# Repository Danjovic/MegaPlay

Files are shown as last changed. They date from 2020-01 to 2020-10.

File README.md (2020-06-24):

# MegaPlay
Sega Genesis/Megadrive controller adapter with keypad emulation for Atari 5200

 This adapter lets you play Atari 5200 using a 6 button Sega Genesis controller yet providing full keypad control.
 
  The circuit is built around an Arduino Nano and two analog multiplexers.
  
  Interface with analog joystick is borrowed from "Low Priced MasterPlay clone adapter" and uses two resistors and a capacitor on each axis to convert the digital directionals into equivalent charging time for minimum, medium and maximum position on each axis.

  Keypad presses are emulated by activating a pair of analog multiplexers. Only 1 (one) keypress can be simulated at a time. 
  When there is no key pressed the "output" multiplexer is inhibited. 
  
  Buttons are mapped as follows:

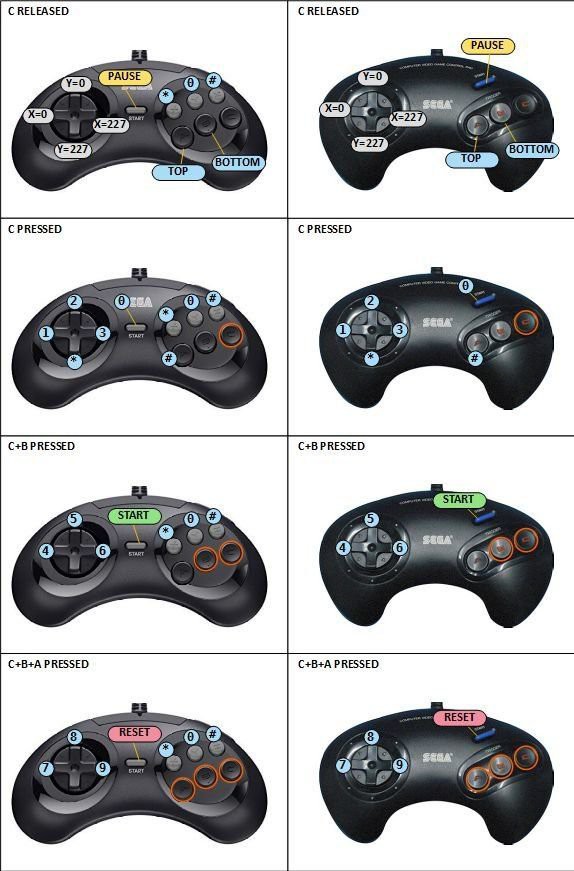
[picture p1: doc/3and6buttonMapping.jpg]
Buttons Mapping


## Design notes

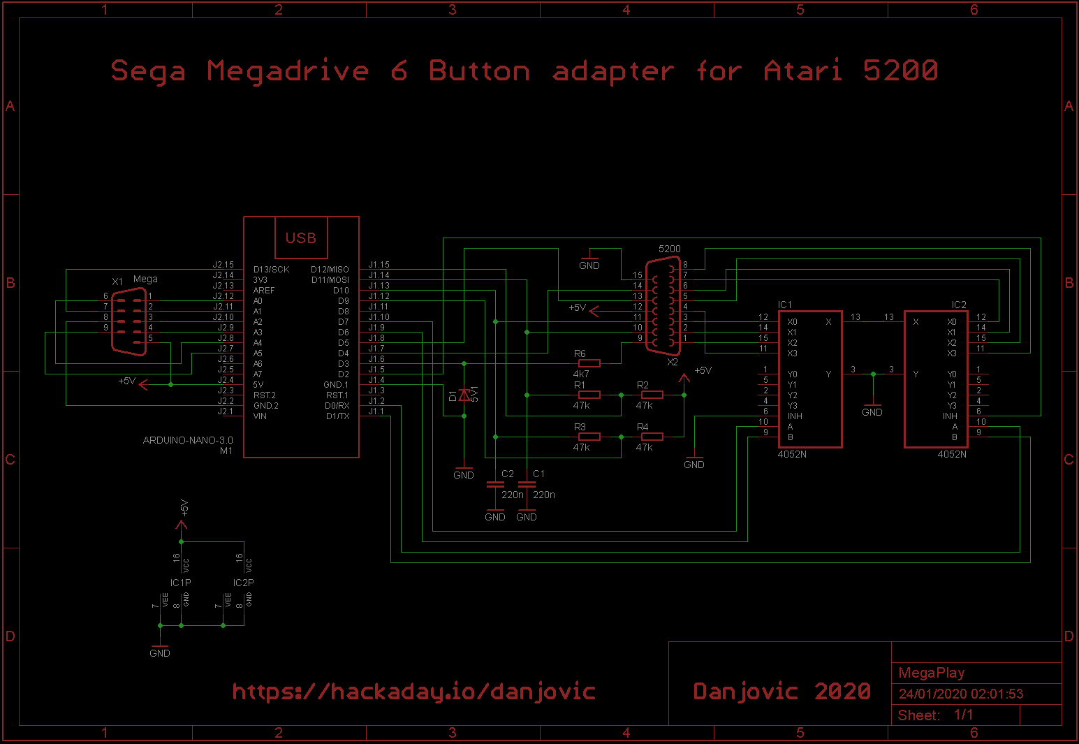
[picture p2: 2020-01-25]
circuit/MegaPlaySchematics.png

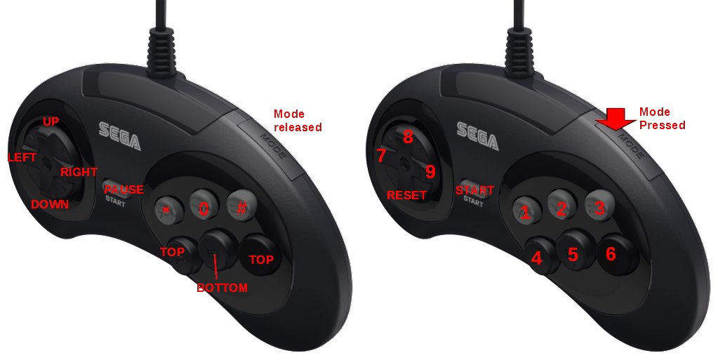
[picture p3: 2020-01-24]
doc/MegaPlay.png

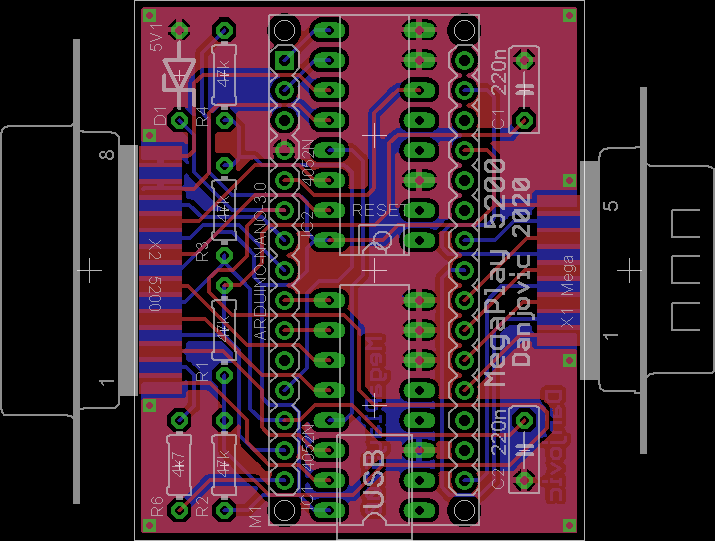
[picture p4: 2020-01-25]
doc/MegaPlayBoard.png

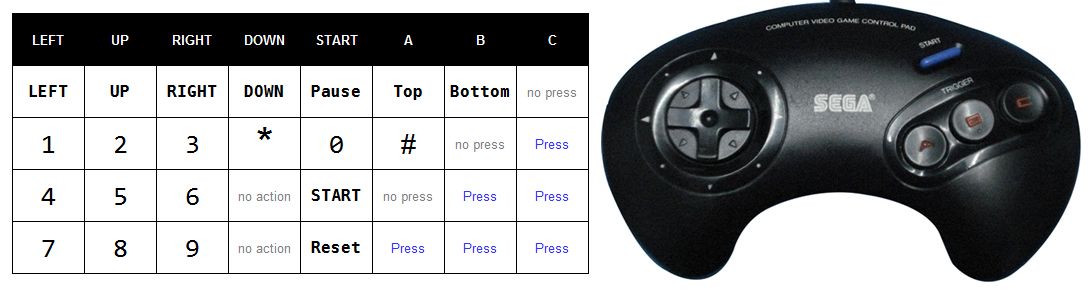
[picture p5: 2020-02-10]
doc/3Button mapping.jpg

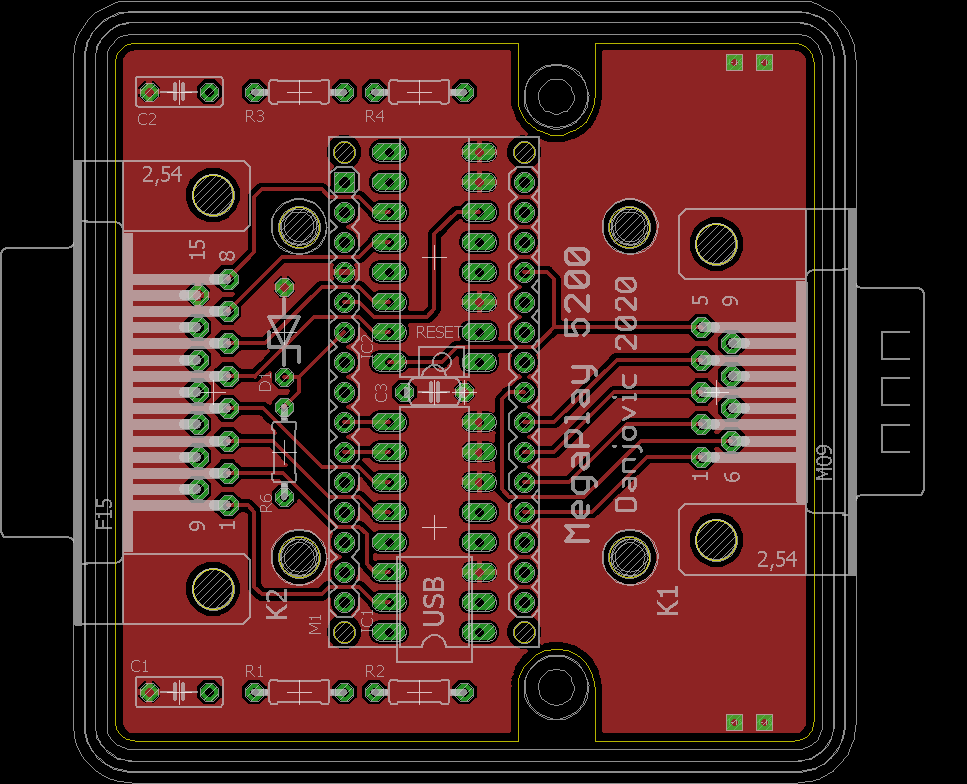
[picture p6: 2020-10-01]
doc/MegaPlayBoard-HammondBox.png

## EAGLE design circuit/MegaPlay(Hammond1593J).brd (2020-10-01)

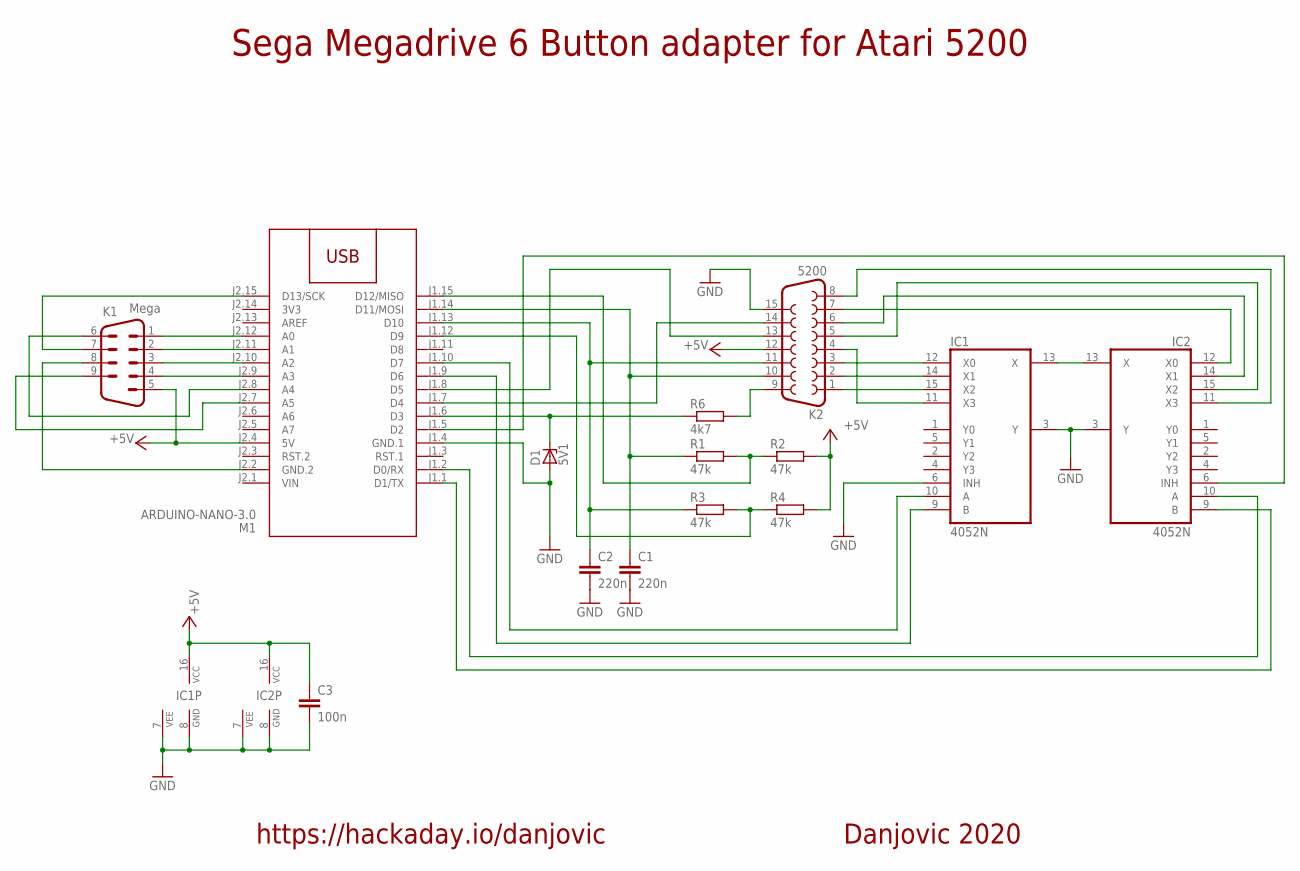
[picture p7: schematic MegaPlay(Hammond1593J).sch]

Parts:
C1, C2: 220n; C050-025X075
C3: 100n; C050-024X044
D1: 5V1; ZDIO-7.5
IC1, IC2: 4052N; DIL16
K1: Mega; M09H
K2: 5200; F15H
M1: ARDUINO-NANO-3.0
R1, R2, R3, R4: 47k; 0204/7
R6: 4k7; 0204/7

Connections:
3V3: M1.J2.14 (3V3)
+5V: C3.1, IC1.16 (VCC), IC2.16 (VCC), K1.5, K2.12, M1.J2.4 (5V), R2.2, R4.2
GND: C1.2, C2.2, C3.2, D1.A, IC1.3 (Y), IC1.6 (INH), IC1.7 (VEE), IC1.8 (GND), IC2.3 (Y), IC2.7 (VEE), IC2.8 (GND), K2.15, M1.J1.4 (GND.1)
unnamed: M1.J1.12 (D9), R3.2, R4.1
unnamed: IC1.15 (X2), K2.1
unnamed: IC1.13 (X), IC2.13 (X)
unnamed: IC1.14 (X1), K2.2
unnamed: IC1.12 (X0), K2.3
unnamed: IC1.11 (X3), K2.4
unnamed: IC2.15 (X2), K2.5
unnamed: IC2.14 (X1), K2.6
unnamed: IC2.12 (X0), K2.7
unnamed: K1.1, M1.J2.12 (A0)
unnamed: C1.1, K2.10, M1.J1.14 (D11/MOSI), R1.1
unnamed: M1.J1.15 (D12/MISO), R1.2, R2.1
unnamed: IC2.11 (X3), K2.8
unnamed: C2.1, K2.11, M1.J1.13 (D10), R3.1
unnamed: K2.13, M1.J1.8 (D5)
unnamed: K1.2, M1.J2.11 (A1)
unnamed: K1.3, M1.J2.10 (A2)
unnamed: K1.4, M1.J2.9 (A3)
unnamed: K1.7, M1.J2.15 (D13/SCK)
unnamed: K1.6, M1.J2.8 (A4)
unnamed: K1.9, M1.J2.7 (A5)
unnamed: K1.8, M1.J2.2 (GND.2)
unnamed: D1.C, M1.J1.6 (D3), R6.1
unnamed: IC2.6 (INH), M1.J1.5 (D2)
unnamed: K2.9, R6.2
unnamed: IC2.10 (A), M1.J1.2 (D0/RX)
unnamed: IC2.9 (B), M1.J1.1 (D1/TX)
unnamed: K2.14, M1.J1.7 (D4)
unnamed: IC1.10 (A), M1.J1.10 (D7)
unnamed: IC1.9 (B), M1.J1.9 (D6)
VIN: M1.J2.1 (VIN)

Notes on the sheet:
Sega Megadrive 6 Button adapter for Atari 5200
Danjovic 2020
https://hackaday.io/danjovic

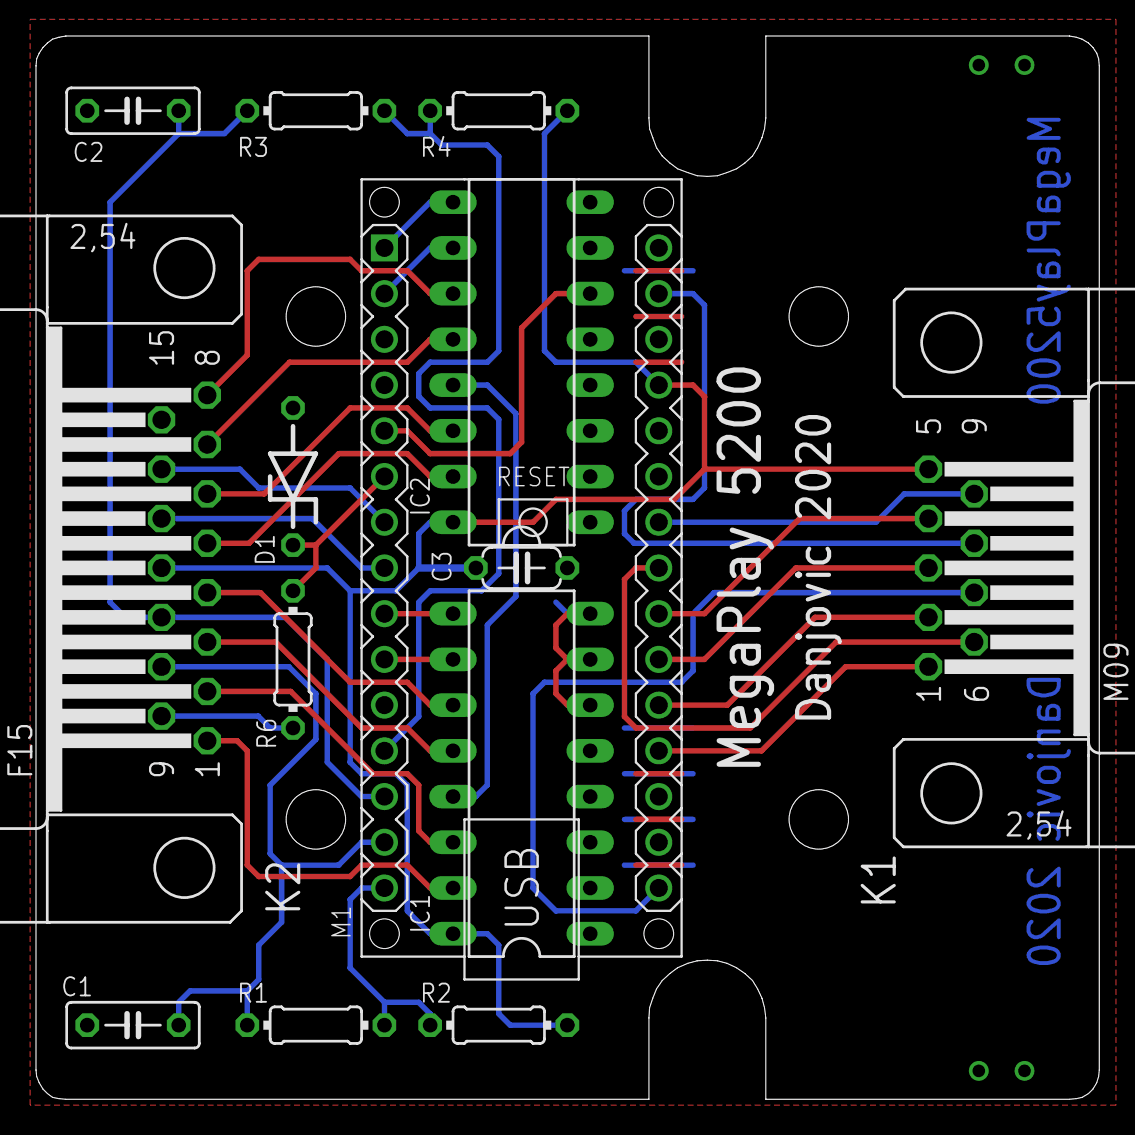
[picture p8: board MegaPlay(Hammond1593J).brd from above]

Board: 2 copper layers, 59.1 x 59.1 mm, 15 parts (0 on the bottom side), 32 nets.

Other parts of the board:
U$1: 1593J

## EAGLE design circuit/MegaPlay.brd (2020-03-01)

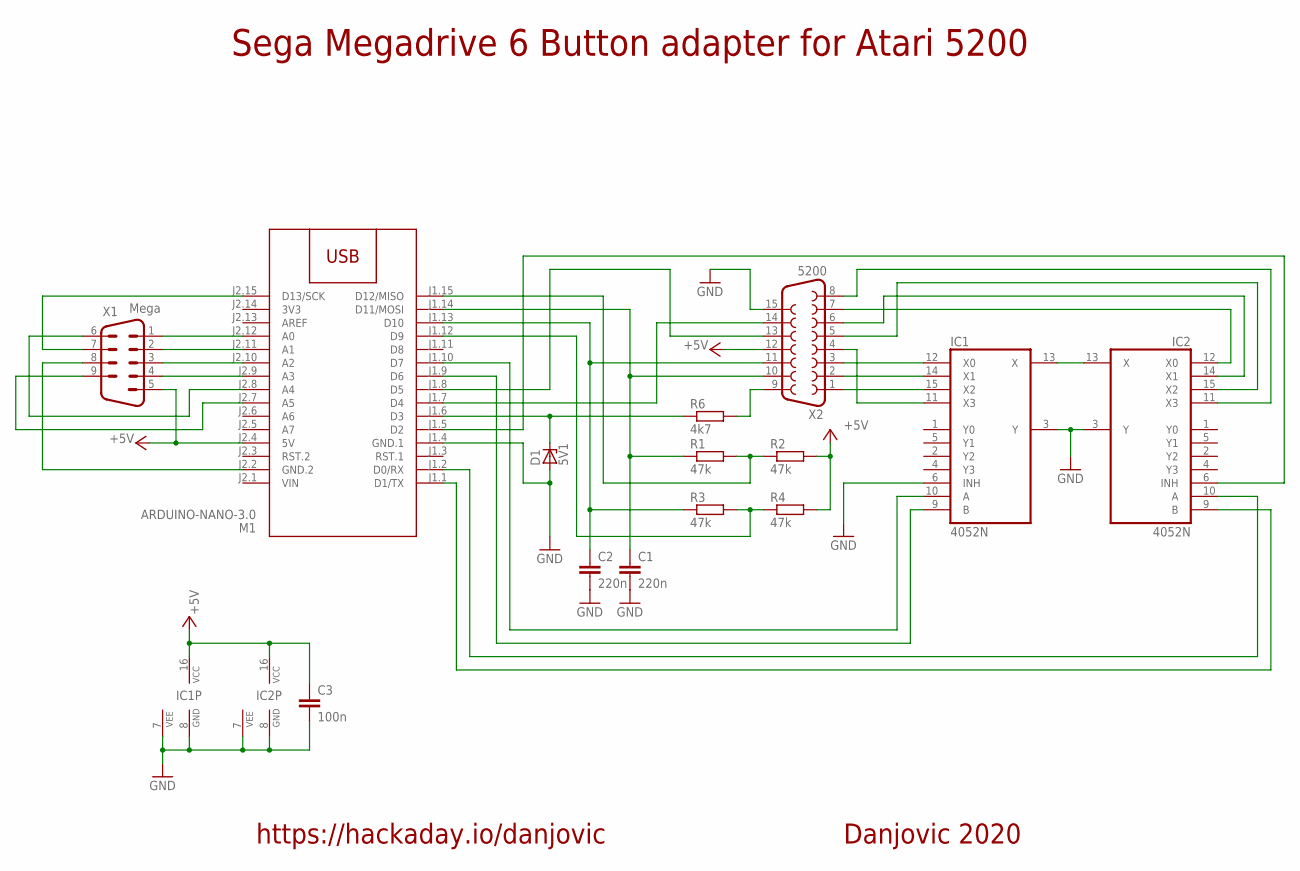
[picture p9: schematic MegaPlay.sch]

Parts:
C1, C2: 220n; C050-025X075
C3: 100n; C050-024X044
D1: 5V1; ZDIO-7.5
IC1, IC2: 4052N; DIL16
M1: ARDUINO-NANO-3.0
R1, R2, R3, R4: 47k; 0204/7
R6: 4k7; 0204/7
X1: Mega; M09D
X2: 5200; F15D

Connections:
3V3: M1.J2.14 (3V3)
+5V: C3.1, IC1.16 (VCC), IC2.16 (VCC), M1.J2.4 (5V), R2.2, R4.2, X1.5, X2.12
GND: C1.2, C2.2, C3.2, D1.A, IC1.3 (Y), IC1.6 (INH), IC1.7 (VEE), IC1.8 (GND), IC2.3 (Y), IC2.7 (VEE), IC2.8 (GND), M1.J1.4 (GND.1), X2.15
unnamed: M1.J1.12 (D9), R3.2, R4.1
unnamed: IC1.15 (X2), X2.1
unnamed: IC1.13 (X), IC2.13 (X)
unnamed: IC1.14 (X1), X2.2
unnamed: IC1.12 (X0), X2.3
unnamed: IC1.11 (X3), X2.4
unnamed: IC2.15 (X2), X2.5
unnamed: IC2.14 (X1), X2.6
unnamed: IC2.12 (X0), X2.7
unnamed: M1.J2.12 (A0), X1.1
unnamed: C1.1, M1.J1.14 (D11/MOSI), R1.1, X2.10
unnamed: M1.J1.15 (D12/MISO), R1.2, R2.1
unnamed: IC2.11 (X3), X2.8
unnamed: C2.1, M1.J1.13 (D10), R3.1, X2.11
unnamed: M1.J1.8 (D5), X2.13
unnamed: M1.J2.11 (A1), X1.2
unnamed: M1.J2.10 (A2), X1.3
unnamed: M1.J2.9 (A3), X1.4
unnamed: M1.J2.15 (D13/SCK), X1.7
unnamed: M1.J2.8 (A4), X1.6
unnamed: M1.J2.7 (A5), X1.9
unnamed: M1.J2.2 (GND.2), X1.8
unnamed: D1.C, M1.J1.6 (D3), R6.1
unnamed: IC2.6 (INH), M1.J1.5 (D2)
unnamed: R6.2, X2.9
unnamed: IC2.10 (A), M1.J1.2 (D0/RX)
unnamed: IC2.9 (B), M1.J1.1 (D1/TX)
unnamed: M1.J1.7 (D4), X2.14
unnamed: IC1.10 (A), M1.J1.10 (D7)
unnamed: IC1.9 (B), M1.J1.9 (D6)
VIN: M1.J2.1 (VIN)

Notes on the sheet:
Sega Megadrive 6 Button adapter for Atari 5200
Danjovic 2020
https://hackaday.io/danjovic

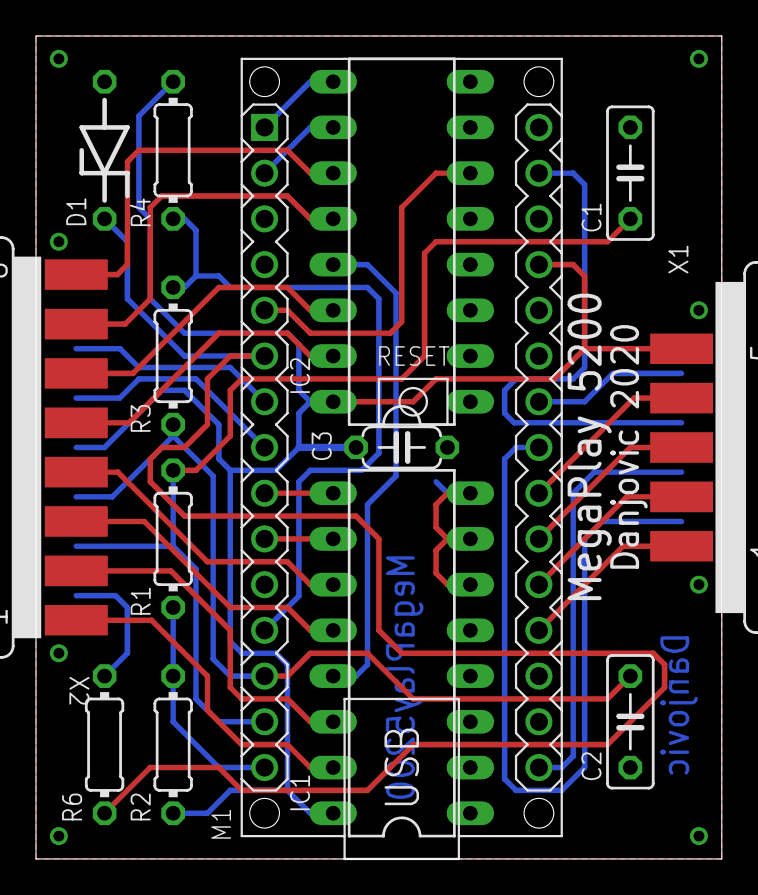
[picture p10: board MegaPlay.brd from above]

Board: 2 copper layers, 38.1 x 45.7 mm, 14 parts (0 on the bottom side), 32 nets.

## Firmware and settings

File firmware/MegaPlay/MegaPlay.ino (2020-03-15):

/*******************************************************************************
       __  __               ___ _           
      |  \/  |___ __ _ __ _| _ \ |__ _ _  _ 
      | |\/| / -_) _` / _` |  _/ / _` | || |
      |_|  |_\___\__, \__,_|_| |_\__,_|\_, |
                 |___/                 |__/ 

  MegaPlay adapter for Atari 5200 - Danjovic 2020 - danjovic@hotmail.com - https://hackaday.io/danjovic

  24 January 2020

  This adapter lets you play Atari 5200 using a 6 button Sega Genesis controller yet providing full keypad control.
  The circuit is built around an Arduino Nano and two analog multiplexers.
  Interface with analog joystick is borrowed from "Low Priced MasterPlay clone adapter" and uses two resistors and
  a capacitor on each axis to convert the digital directionals into equivalent charging time for minimum, medium and 
  maximum position on each axis.

  Keypad presses are emulated by activating a pair of analog multiplexers. Only 1 (one) keypress can be simulated at a time. 
  When there is no key pressed the "output" multiplexer is inhibited. Buttons are mapped as follows:

                    +------------------------------------------+
                    |           Modifier key(s) pressed        |
+----------+--------+-----------+----------+---------+---------+
|   Type   | Button |   none    |    C     |  C + B  |  C+B+A  |
+-----+----+--------+ ----------+----------+---------+---------+
|  6  | 3  | UP     |    UP     |    2     |    5    |    8    |
|  B  | B  | DOWN   |   DOWN    |    *     |    -    |    -    |
|  u  | u  | LEFT   |   LEFT    |    1     |    4    |    7    |
|  t  | t  | RIGHT  |   RIGHT   |    3     |    6    |    9    |
|  t  | t  |  A     |    Top    |    #     |    -    |    -    |
|  o  | o  |  B     |   Bottom  |    -     |    -    |    -    |
|  n  | n  |  C     |     -     |    -     |    -    |    -    |
|     |    | START  |   Pause   |    0     |  Start  |  Reset  |
|     +----+--------+-----------+----------+---------+---------+
|          |  X     |     *     |    *     |    *    |    *    |
|          |  Y     |     0     |    0     |    0    |    0    |
|          |  Z     |     #     |    #     |    #    |    #    |
+----------+--------+-----------+----------+---------+---------+ 

  Keypresses are emulated by activation of the following combination of signals. 
  The 'none' key state is issued by rising the INHIBT signal to disabe the output MUX.

        +------- Output Mux -MSbits-----+
  Input |   7       6       5       8   |
   Mux  |  0 0  |  0 1  |  1 0  |  1 1  |
   B A  +-------+-------+-------+-------+ 
   0 0  |   1   |   4   |   7   |   *   | 3
   0 1  |   2   |   5   |   8   |   0   | 2
   1 0  |   3   |   6   |   9   |   #   | 1
   1 1  | start | pause | reset |  none | 4
        +-------+-------+-------+-------+

  CAV Voltage on PIN 9 is connected to INT1 IRQ pin and is used to promptly turn off the timing pins whenever CAV drops to zero. 
  A zener diode as added to protect the AVR input, as the CAV voltage can reach up to 6.4Volts.



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
*/




/*******************************************************************************
 *         _      __ _      _ _   _             
 *      __| |___ / _(_)_ _ (_) |_(_)___ _ _  ___
 *     / _` / -_)  _| | ' \| |  _| / _ \ ' \(_-<
 *     \__,_\___|_| |_|_||_|_|\__|_\___/_||_/__/
 *                                              
 */

//#define DEBUG 1

 
#define _key1        ((0<<3)|(0<<2)|(0<<1)|(0<<0)) // 0
#define _key2        ((0<<3)|(0<<2)|(0<<1)|(1<<0)) // 1
#define _key3        ((0<<3)|(0<<2)|(1<<1)|(0<<0)) // 2
#define _keyStart    ((0<<3)|(0<<2)|(1<<1)|(1<<0)) // 3
#define _key4        ((0<<3)|(1<<2)|(0<<1)|(0<<0)) // 4
#define _key5        ((0<<3)|(1<<2)|(0<<1)|(1<<0)) // 5
#define _key6        ((0<<3)|(1<<2)|(1<<1)|(0<<0)) // 6
#define _keyPause    ((0<<3)|(1<<2)|(1<<1)|(1<<0)) // 7
#define _key7        ((1<<3)|(0<<2)|(0<<1)|(0<<0)) // 8
#define _key8        ((1<<3)|(0<<2)|(0<<1)|(1<<0)) // 9
#define _key9        ((1<<3)|(0<<2)|(1<<1)|(0<<0)) // 10
#define _keyReset    ((1<<3)|(0<<2)|(1<<1)|(1<<0)) // 11
#define _keyAsterisk ((1<<3)|(1<<2)|(0<<1)|(0<<0)) // 12
#define _key0        ((1<<3)|(1<<2)|(0<<1)|(1<<0)) // 13
#define _keyHash     ((1<<3)|(1<<2)|(1<<1)|(0<<0)) // 14
#define _keyNone     ((1<<3)|(1<<2)|(1<<1)|(1<<0)) // 15

#define inputMuxA       6
#define inputMuxB       7
#define outputMuxA      0
#define outputMuxB      1
#define outputMuxInhibt 2

#define genesisUp       A0
#define genesisDown     A1
#define genesisLeft     A2
#define genesisRigth    A3
#define genesisB        A4
#define genesisC        A5
#define genesisSelect   13

#define potXfull        11
#define potXhalf        12

#define potYfull        10
#define potYhalf        9

#define fireTop         4
#define fireBottom      5

enum controllerType {
  _6Button=0,
  _3Button,
  _unKnown =0xff
  };

#define buttonUp     (1<<0)
#define buttonDown   (1<<1)
#define buttonLeft   (1<<2)
#define buttonRight  (1<<3)
#define buttonB      (1<<4)
#define buttonC      (1<<5)
#define buttonA      (1<<6)
#define buttonStart  (1<<7)
#define buttonZ      (1<<8)
#define buttonY      (1<<9)
#define buttonX      (1<<10)
#define buttonMode   (1<<11)

/*******************************************************************************
 *                   _      _    _        
 *     __ ____ _ _ _(_)__ _| |__| |___ ___
 *     \ V / _` | '_| / _` | '_ \ / -_|_-<
 *      \_/\__,_|_| |_\__,_|_.__/_\___/__/
 *                                        
 */

uint8_t ScanGenesis(void);
void assertTopFire(void);
void releaseTopFire(void);
void assertBottomFire(void);
void releaseBottomFire(void);
void setMinimumY(void);
void setMaximumY(void);
void setMiddleY(void); 
void setMinimumX(void);
void setMaximumX(void);
void setMiddleX(void); 

static volatile uint8_t CAVoff;
uint16_t combinedButtons = 0;



/*******************************************************************************
 *      _     _                         _      
 *     (_)_ _| |_ ___ _ _ _ _ _  _ _ __| |_ ___
 *     | | ' \  _/ -_) '_| '_| || | '_ \  _(_-<
 *     |_|_||_\__\___|_| |_|  \_,_| .__/\__/__/
 *                                |_|          
 */

// External interrupt, triggers every time CAV voltage changes state.
ISR (INT1_vect, ISR_NAKED) { 
  asm volatile (
    "push __tmp_reg__\n\t"         //
    "in __tmp_reg__,__SREG__\n\t"  //  Save Context
    "push __tmp_reg__\n\t"         //  
    "clr __tmp_reg__\n\t"         // temp_reg=0 CAVoff = false
    "sbic %[PORTIN],3 \n\t"       // CAV has dropped?
    "rjmp _STORE\n\t"             // no update value
    "cbi %[PORTPOTS],2\n\t"       // yes, force pin Y to zero
    "sbi %[DDRPOTS],2\n\t"
    "cbi %[PORTPOTS],3\n\t"       // yes, force pin X to zero
    "sbi %[DDRPOTS],3\n\t"
    "inc __tmp_reg__\n\t"         // temp_reg=1 CAVoff = true                        
    "_STORE:\n\t"
     "sts %[flagCAVoff],__tmp_reg__\n\t" // store CAVoff flag value
    "pop __tmp_reg__\n\t"           //
    "out __SREG__,__tmp_reg__\n\t"  // Restore Context
    "pop __tmp_reg__\n\t"           //
    "reti \n\t"
    :[flagCAVoff] "=m"(CAVoff)
    :[PORTIN]"I" (_SFR_IO_ADDR(PIND)),[DDRPOTS]"I" (_SFR_IO_ADDR(DDRB)) ,[PORTPOTS]"I" (_SFR_IO_ADDR(PORTB)) 
    );  
  }



/*******************************************************************************
 *      ___      _             
 *     / __| ___| |_ _  _ _ __ 
 *     \__ \/ -_)  _| || | '_ \
 *     |___/\___|\__|\_,_| .__/
 *                       |_|   
 */
void setup() {
  // put your setup code here, to run once:

  pinMode(potXfull,INPUT);
  pinMode(potXhalf,OUTPUT);
  digitalWrite(potXhalf,HIGH);
  
  pinMode(potYfull,INPUT);
  pinMode(potYhalf,OUTPUT);
  digitalWrite(potYhalf,HIGH);  

  
  pinMode(genesisUp    ,INPUT_PULLUP);
  pinMode(genesisDown  ,INPUT_PULLUP);
  pinMode(genesisLeft  ,INPUT_PULLUP);
  pinMode(genesisRigth ,INPUT_PULLUP);
  pinMode(genesisB     ,INPUT_PULLUP);
  pinMode(genesisC     ,INPUT_PULLUP);
  pinMode(genesisSelect,OUTPUT);
  digitalWrite(genesisSelect,LOW);
  pinMode(outputMuxB,OUTPUT); 
  pinMode(outputMuxA,OUTPUT); 
  pinMode(inputMuxB,OUTPUT); 
  pinMode(inputMuxA,OUTPUT);   
  pinMode(outputMuxInhibt,OUTPUT);
  digitalWrite(outputMuxInhibt,HIGH);
  delay(5); // wait for genesis internal logic timeout

 
  // Setup interrupts
  EICRA = (0<<ISC11)| (1<<ISC10); //  Any logical change on INT1 generates an interrupt request.
  EIMSK = (1<<INT1);              //  enable external interrupts on pin INT1 (D3)
  EIFR =  (1<<INT1); // clear any pending interrupt
  
  sei();  // enable interrupts
#ifdef DEBUG
  Serial.begin(9600);
#endif
}




/*******************************************************************************
 *      __  __      _        _                  
 *     |  \/  |__ _(_)_ _   | |   ___  ___ _ __ 
 *     | |\/| / _` | | ' \  | |__/ _ \/ _ \ '_ \
 *     |_|  |_\__,_|_|_||_| |____\___/\___/ .__/
 *                                        |_|   
 */
void loop() {
  uint8_t controllerType; 
  controllerType = ScanGenesis();
    
#ifdef DEBUG    
    Serial.print("Type:");
    switch (controllerType) {
      case _6Button:
          Serial.print ("6 button ");
          break;
      case _3Button:
          Serial.print ("3 button ");
          break;
      default:
          Serial.print ("Master/unknown ");
          break;                    
      }
     Serial.print  ("buttons:");
     Serial.print   ((combinedButtons | (1<<15)),BIN);
#endif

//controllerType = _3Button;  // fake 3 button for testing only 

  if ( controllerType == _6Button)   {  // do 6 Button Stuff

    if (combinedButtons & buttonC )  {  // Modifier key pressed  
	   if (combinedButtons & buttonB) {  // Second modifier key pressed  
	      if (combinedButtons & buttonA) { // Third modifier key pressed (C+B+A)
		  // C+B+A pressed
		  combinedButtons &= ~(buttonC | buttonB | buttonA); // clear modifier buttons bits 
				switch (combinedButtons) {
					case buttonLeft:  // keypad 7
					   setKeypad (_key7);
					   break;		
					case buttonUp:    // keypad 8
					   setKeypad (_key8);
					   break;		
					case buttonRight: // keypad 9
					   setKeypad (_key9);
					   break;		
//			case buttonDown:  // keypad * 
//			   setKeypad (_keyAsterisk);
//			   break;
					case buttonStart:     // Reset
					   setKeypad (_keyReset);
					   break; 
//			case buttonA:     // keypad #
//			   setKeypad (_keyHash);
//			   break;
					default:       // None or multiple
					   setKeypad (_keyNone);		   
				} // switch			
		  } else { // C+B modifier keys pressed
		  combinedButtons &= ~(buttonC | buttonB); // clear modifier buttons bits 
				switch (combinedButtons) {
					case buttonLeft:  // keypad 4
					   setKeypad (_key4);
					   break;		
					case buttonUp:    // keypad 5
					   setKeypad (_key5);
					   break;		
					case buttonRight: // keypad 6
					   setKeypad (_key6);
					   break;		
//			case buttonDown:  // keypad * 
//			   setKeypad (_keyAsterisk);
//			   break;
					case buttonStart:     // Start
					   setKeypad (_keyStart);
					   break; 
//			case buttonA:     // keypad #
//			   setKeypad (_keyHash);
//			   break;
					default:       // None or multiple
					   setKeypad (_keyNone);		   
				} // switch	
		  } // else
		   
	} else { // Only C modifier key pressed
	combinedButtons &= ~(buttonC); // clear modifier buttons bits 		
		switch (combinedButtons) {
			case buttonLeft:  // keypad 1
			   setKeypad (_key1);
			   break;		
			case buttonUp:    // keypad 2
			   setKeypad (_key2);
			   break;		
			case buttonRight: // keypad 3
			   setKeypad (_key3);
			   break;		
			case buttonDown:  // keypad * 
			   setKeypad (_keyAsterisk);
			   break;
			case buttonStart: // keypad 0
			   setKeypad (_key0);
			   break; 
			case buttonA:     // keypad #
			   setKeypad (_keyHash);
			   break;
			default:       // None or multiple
			   setKeypad (_keyNone);		   
		} // switch	
	} // else
	

    } else { // Mode button released
      switch(combinedButtons) {
        case buttonX:     // keypad * 
           setKeypad (_keyAsterisk);
           break;    
        case buttonY:     // keypad 0
           setKeypad (_key0);
           break;    
        case buttonZ:     // keypad #
           setKeypad (_keyHash);
           break;
        case buttonStart: // Pause
           setKeypad (_keyPause);
           break;
        default:       // None or multiple
           setKeypad (_keyNone);
      } // switch
      
      // Take care of buttons
      if (combinedButtons & buttonA  ) assertTopFire(); else releaseTopFire();	  
      if (combinedButtons &  buttonB ) assertBottomFire(); else releaseBottomFire();
      
      // Take care of directionals
   // Activate 5200 port accordingly 
     if ((combinedButtons & buttonUp) && (combinedButtons & buttonDown)) // if both UP and DOWN go to middle
          setMiddleY(); 
     else 
        if ( combinedButtons & buttonUp    ) 
          setMinimumY();
     else if ( combinedButtons & (buttonDown)  ) 
          setMaximumY();
     else setMiddleY(); 
  
     // Activate 5200 port accordingly 
     if ((combinedButtons & buttonLeft) && (combinedButtons & buttonRight) ) // if both UP and DOWN go to middle
          setMiddleX(); 
     else 
        if ( combinedButtons & buttonLeft    ) 
          setMinimumX();
     else if ( combinedButtons & (buttonRight)  ) 
          setMaximumX();
     else setMiddleX(); 
  
    } // end of 6 button controller handling
	
	

  } else if (controllerType == _3Button ) { // work with 3 button, limited functionality
    

    if (combinedButtons & buttonC )  {  // Modifier key pressed  
	   if (combinedButtons & buttonB) {  // Second modifier key pressed  
	      if (combinedButtons & buttonA) { // Third modifier key pressed (C+B+A)
		  // C+B+A pressed
		  combinedButtons &= ~(buttonC | buttonB | buttonA); // clear modifier buttons bits 
				switch (combinedButtons) {
					case buttonLeft:  // keypad 7
					   setKeypad (_key7);
					   break;		
					case buttonUp:    // keypad 8
					   setKeypad (_key8);
					   break;		
					case buttonRight: // keypad 9
					   setKeypad (_key9);
					   break;		
//			case buttonDown:  // keypad * 
//			   setKeypad (_keyAsterisk);
//			   break;
					case buttonStart:     // Reset
					   setKeypad (_keyReset);
					   break; 
//			case buttonA:     // keypad #
//			   setKeypad (_keyHash);
//			   break;
					default:       // None or multiple
					   setKeypad (_keyNone);		   
				} // switch			
		  } else { // C+B modifier keys pressed
		  combinedButtons &= ~(buttonC | buttonB); // clear modifier buttons bits 
				switch (combinedButtons) {
					case buttonLeft:  // keypad 4
					   setKeypad (_key4);
					   break;		
					case buttonUp:    // keypad 5
					   setKeypad (_key5);
					   break;		
					case buttonRight: // keypad 6
					   setKeypad (_key6);
					   break;		
//			case buttonDown:  // keypad * 
//			   setKeypad (_keyAsterisk);
//			   break;
					case buttonStart:     // Start
					   setKeypad (_keyStart);
					   break; 
//			case buttonA:     // keypad #
//			   setKeypad (_keyHash);
//			   break;
					default:       // None or multiple
					   setKeypad (_keyNone);		   
				} // switch	
		  } // else
		   
	} else { // Only C modifier key pressed
	combinedButtons &= ~(buttonC); // clear modifier buttons bits 		
		switch (combinedButtons) {
			case buttonLeft:  // keypad 1
			   setKeypad (_key1);
			   break;		
			case buttonUp:    // keypad 2
			   setKeypad (_key2);
			   break;		
			case buttonRight: // keypad 3
			   setKeypad (_key3);
			   break;		
			case buttonDown:  // keypad * 
			   setKeypad (_keyAsterisk);
			   break;
			case buttonStart: // keypad 0
			   setKeypad (_key0);
			   break; 
			case buttonA:     // keypad #
			   setKeypad (_keyHash);
			   break;
			default:       // None or multiple
			   setKeypad (_keyNone);		   
		} // switch	
	} // else
		
	} else { // No modifier key pressed
	
      // Take care of Start Button		
      if (combinedButtons & buttonStart) setKeypad (_keyPause); else setKeypad (_keyNone);
	  
      // Take care of buttons
      if (combinedButtons & (buttonA ) ) assertTopFire(); else releaseTopFire();
      if (combinedButtons &  buttonB ) assertBottomFire(); else releaseBottomFire();
      
      // Take care of directionals
   // Activate 5200 port accordingly 
     if ((combinedButtons & buttonUp) && (combinedButtons & buttonDown )) // if both UP and DOWN go to middle
          setMiddleY(); 
     else 
        if ( combinedButtons & buttonUp    ) 
          setMaximumY();
     else if ( combinedButtons & (buttonDown)  ) 
          setMaximumY();
     else setMiddleY(); 
  
     // Activate 5200 port accordingly 
     if ((combinedButtons & buttonLeft) && (combinedButtons & buttonRight)) // if both UP and DOWN go to middle
          setMiddleX(); 
     else 
        if ( combinedButtons & buttonLeft    ) 
          setMaximumX();
     else if ( combinedButtons & (buttonRight)  ) 
          setMaximumX();
     else setMiddleX(); 
	  
	}  // end of 3 button controller handling

      
  } else { // No controller detected, 
    setKeypad (_keyNone);
    setMiddleX();
    setMiddleY();
    releaseBottomFire();
    releaseTopFire();
    delay(100);
  }
  delay(8); // 8 milliseconds between readings.

}



/*******************************************************************************
 *       __              _   _             
 *      / _|_  _ _ _  __| |_(_)___ _ _  ___
 *     |  _| || | ' \/ _|  _| / _ \ ' \(_-<
 *     |_|  \_,_|_||_\__|\__|_\___/_||_/__/
 *                                         
 */

void setKeypad ( uint8_t keyCode) {
  char key[16]={"123S456P789R*0#N"};
#ifdef DEBUG  
  Serial.print (" Key:");
  Serial.print (keyCode);
  Serial.print ("->");  
  Serial.println (key[keyCode]);
#endif
  if (keyCode & (1<<3) ) digitalWrite(outputMuxB,HIGH); else digitalWrite(outputMuxB,LOW);
  if (keyCode & (1<<2) ) digitalWrite(outputMuxA,HIGH); else digitalWrite(outputMuxA,LOW); 
  
  if (keyCode & (1<<1) ) digitalWrite(inputMuxB,HIGH); else digitalWrite(inputMuxB,LOW);
  if (keyCode & (1<<0) ) digitalWrite(inputMuxA,HIGH); else digitalWrite(inputMuxA,LOW);

  if ( keyCode == _keyNone ) {
    digitalWrite(outputMuxInhibt,HIGH);  // inhibt output 
  } else {
    digitalWrite(outputMuxInhibt,LOW);   
  }
}



//
//
void setMinimumX(void) {
  if (!CAVoff) {
    digitalWrite(potXfull,HIGH);
    pinMode(potXfull,OUTPUT);
  }
}

//
//
void setMaximumX(void) {
  if (!CAVoff) {
    pinMode(potXhalf,INPUT);
    digitalWrite(potXhalf,LOW); // turn off pullup
    pinMode(potXfull,INPUT);
    digitalWrite(potXfull,LOW);  // turn off pullup
  } 
}

//
//
void setMiddleX(void){
  if (!CAVoff) {
    pinMode(potXfull,INPUT);
    digitalWrite(potXfull,LOW);  // turn off pullup   
    digitalWrite(potXhalf,HIGH);    
    pinMode(potXhalf,OUTPUT);
  } 
}

//
//
void setMinimumY(void) {
  if (!CAVoff) {
    digitalWrite(potYfull,HIGH);
    pinMode(potYfull,OUTPUT);
  }
}

//
//
void setMaximumY(void) {
  if (!CAVoff) {
    pinMode(potYhalf,INPUT);
    digitalWrite(potYhalf,LOW); // turn off pullup
    pinMode(potYfull,INPUT);
    digitalWrite(potYfull,LOW);  // turn off pullup
  } 
}

//
//
void setMiddleY(void){
  if (!CAVoff) {
    pinMode(potYfull,INPUT);
    digitalWrite(potYfull,LOW);  // turn off pullup   
    digitalWrite(potYhalf,HIGH);    
    pinMode(potYhalf,OUTPUT);
  } 
}

//
//
void assertTopFire(void) {
  digitalWrite(fireTop,LOW); // turn off pullup
  pinMode(fireTop,OUTPUT);   
}

//
//
void releaseTopFire(void) {
  pinMode(fireTop,INPUT);
  digitalWrite(fireTop,HIGH); // turn on pullup
}

//
//
void assertBottomFire(void) {
  digitalWrite(fireBottom,LOW); // turn off pullup
  pinMode(fireBottom,OUTPUT);   
}

//
//
void releaseBottomFire(void) {
  pinMode(fireBottom,INPUT);
  digitalWrite(fireBottom,HIGH); // turn on pullup
}

//
//
uint8_t ScanGenesis(void) {

  uint8_t sample[7]; 
  uint8_t type;  
  combinedButtons = 0;
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

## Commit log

2020-01-24 Added files
    Files added only. Not tested code.
    [MegaPlay.brd, MegaPlay.sch]
2020-03-01 Added decoupling capacitor to Analog Switches power supply.
    [MegaPlay.brd, MegaPlay.sch]
2020-03-02 Added support for 6 button controller without MODE key
2020-03-15 corrected button assignment table in comments
    [MegaPlay.ino]
2020-10-01 Added PCB version for Hammond 1593J box
    [MegaPlay(Hammond1593J).brd, MegaPlay(Hammond1593J).sch]

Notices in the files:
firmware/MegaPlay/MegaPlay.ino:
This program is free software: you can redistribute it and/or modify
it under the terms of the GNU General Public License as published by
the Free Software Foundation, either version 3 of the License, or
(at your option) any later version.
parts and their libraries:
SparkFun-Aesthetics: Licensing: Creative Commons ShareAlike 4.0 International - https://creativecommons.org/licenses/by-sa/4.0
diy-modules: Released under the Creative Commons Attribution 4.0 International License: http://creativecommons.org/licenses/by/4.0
